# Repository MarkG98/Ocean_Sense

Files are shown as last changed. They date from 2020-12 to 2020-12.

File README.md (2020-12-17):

# Ocean_Sense

Ocean Sense is an ocean-sensing platform which can be placed on a buoy or other ocean science apparatus and sent out to sea for about one week at a time. Many ocean science experiments are run off of buoys or other devices that stand alone in the field for an extended period of time. This board serves as a packaged sensor set that measures and logs three local conditions during the experiments: **temperature, humidity**, and **acceleration**. The board sits ontop of a buoy or equivalent flotation device for the duration of an experiment and then is retrieved. To travel into the depths of the ocean, an appropriate case will need to be engineered.

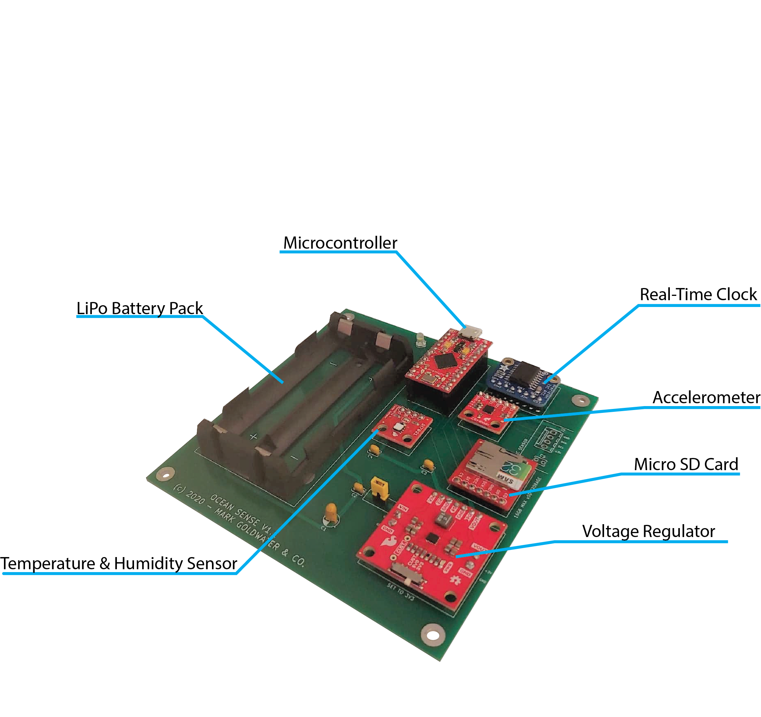
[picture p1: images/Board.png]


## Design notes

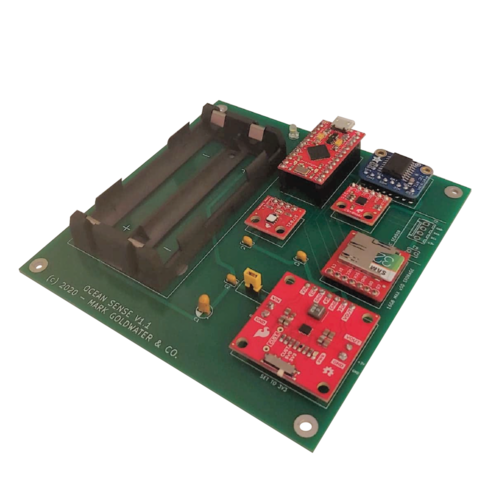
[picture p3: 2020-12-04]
images/BoardCoverView.png

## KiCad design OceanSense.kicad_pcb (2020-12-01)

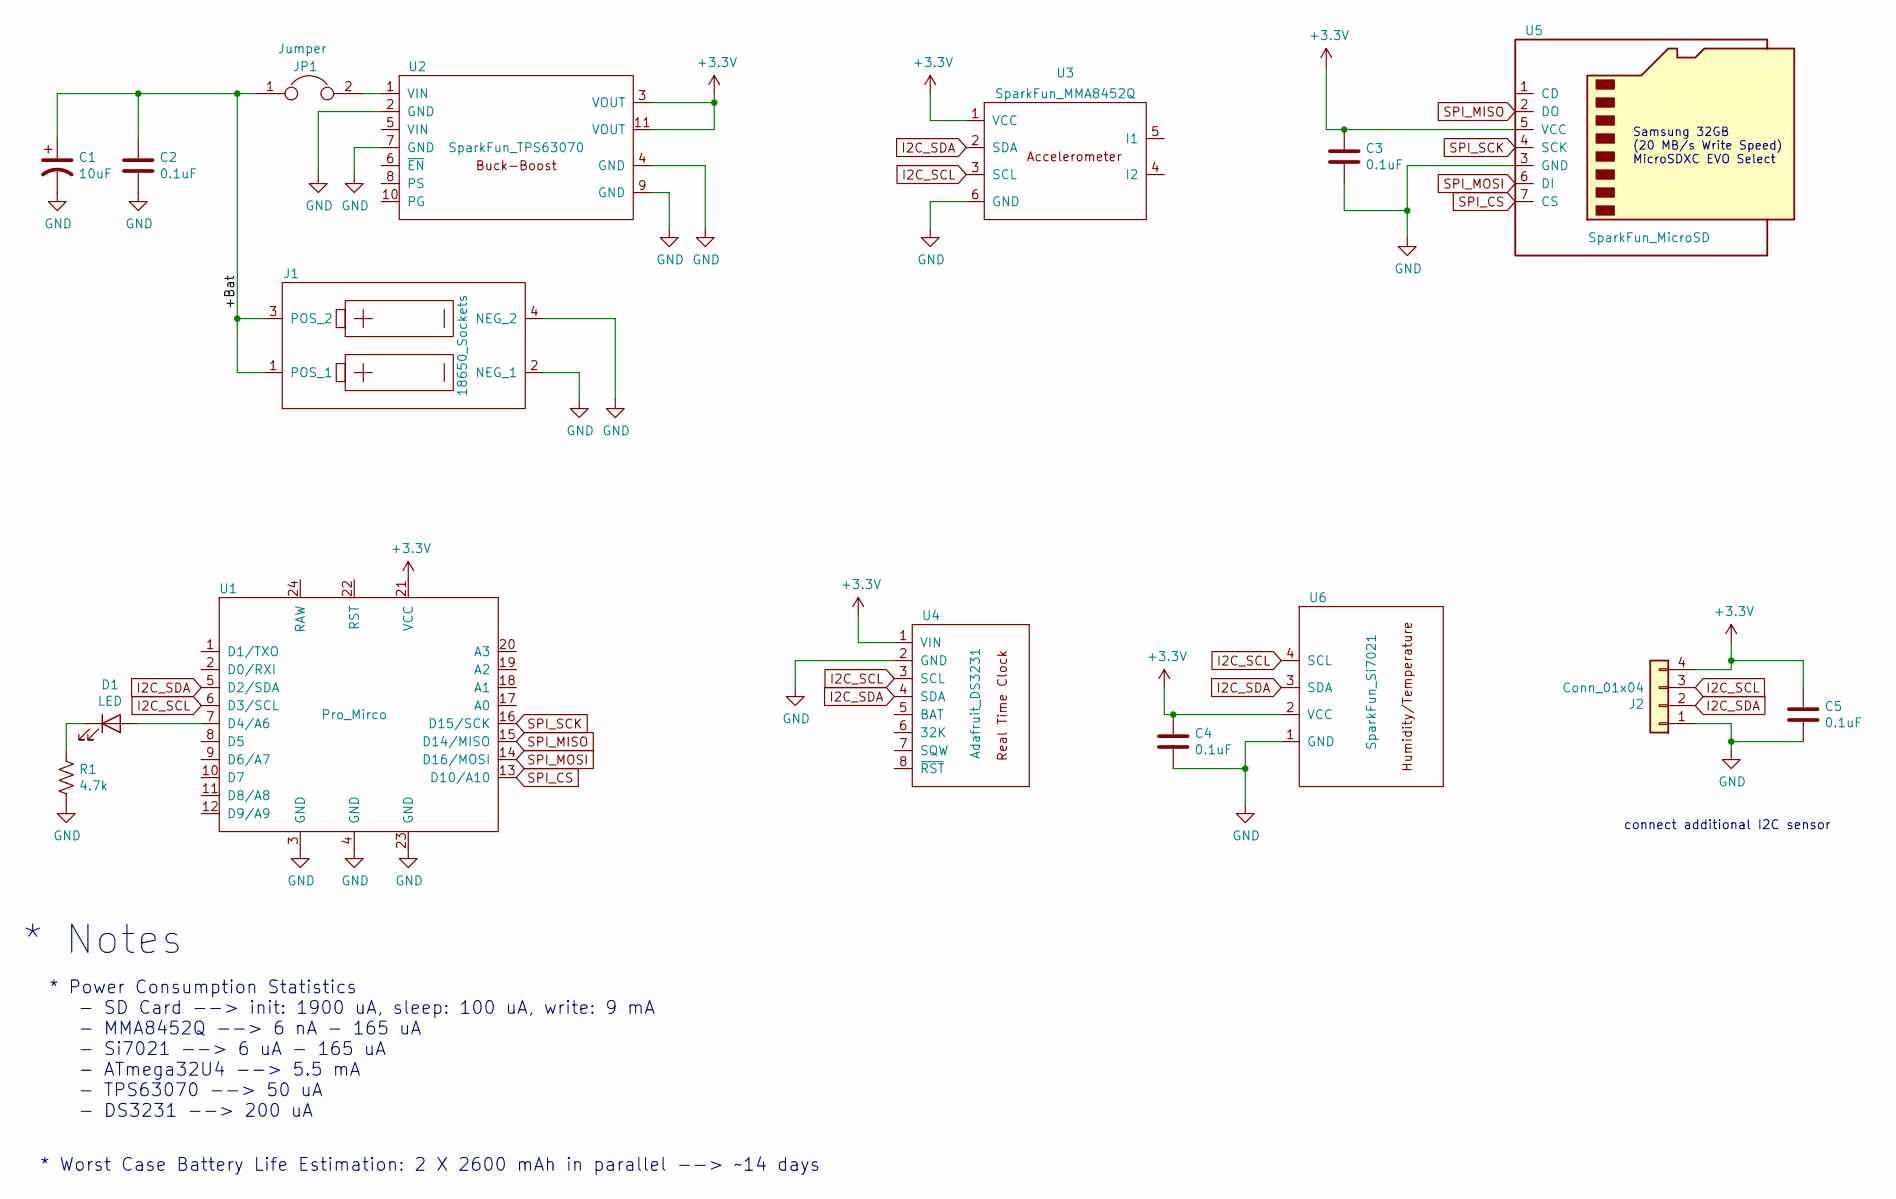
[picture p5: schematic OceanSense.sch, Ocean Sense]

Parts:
C1: 10uF; CP_Radial_D5.0mm_P2.50mm
C2, C3, C4, C5: 0.1uF; C_Rect_L4.0mm_W2.5mm_P2.50mm
D1: LED; LED_D3.0mm
J1: 18650_Sockets; 36-1049-ND
J2: Conn_01x04; Molex_KK-254_AE-6410-04A_1x04_P2.54mm_Vertical
JP1: Jumper
R1: 4.7k; Resistor
U1: Pro_Mirco; Pro Micro
U2: SparkFun_TPS63070; TPS63070
U3: SparkFun_MMA8452Q; MMA8452Q
U4: Adafruit_DS3231; DS3231
U5: SparkFun_MicroSD; uSD Breakout
U6: SparkFun_Si7021; Si7021

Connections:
+3V3: C3.1, C4.1, C5.1, J2.4, U1.21 (VCC), U2.3 (VOUT), U2.11 (VOUT), U3.1 (VCC), U4.1 (VIN), U5.5 (VCC), U6.2 (VCC)
/+Bat: C1.1, C2.1, J1.1 (POS_1), J1.3 (POS_2), JP1.1
GND: C1.2, C2.2, C3.2, C4.2, C5.2, J1.2 (NEG_1), J1.4 (NEG_2), J2.1, R1.2, U1.3 (GND), U1.4 (GND), U1.23 (GND), U2.2 (GND), U2.4 (GND), U2.7 (GND), U2.9 (GND), U3.6 (GND), U4.2 (GND), U5.3 (GND), U6.1 (GND)
I2C_SCL: J2.3, U1.6 (D3/SCL), U3.3 (SCL), U4.3 (SCL), U6.4 (SCL)
I2C_SDA: J2.2, U1.5 (D2/SDA), U3.2 (SDA), U4.4 (SDA), U6.3 (SDA)
unnamed: D1.1 (K), R1.1
unnamed: D1.2 (A), U1.7 (D4/A6)
unnamed: JP1.2, U2.1 (VIN)
SPI_CS: U1.13 (D10/A10), U5.7 (CS)
SPI_MISO: U1.15 (D14/MISO), U5.2 (DO)
SPI_MOSI: U1.14 (D16/MOSI), U5.6 (DI)
SPI_SCK: U1.16 (D15/SCK), U5.4 (SCK)

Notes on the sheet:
* Power Consumption Statistics - SD Card --> init: 1900 uA, sleep: 100 uA, write: 9 mA - MMA8452Q --> 6 nA - 165 uA - Si7021 --> 6 uA - 165 uA - ATmega32U4 --> 5.5 mA - TPS63070 --> 50 uA - DS3231 --> 200 uA
Samsung 32GB (20 MB/s Write Speed) MicroSDXC EVO Select
* Worst Case Battery Life Estimation: 2 X 2600 mAh in parallel --> ~~14 days
* Notes
connect additional I2C sensor

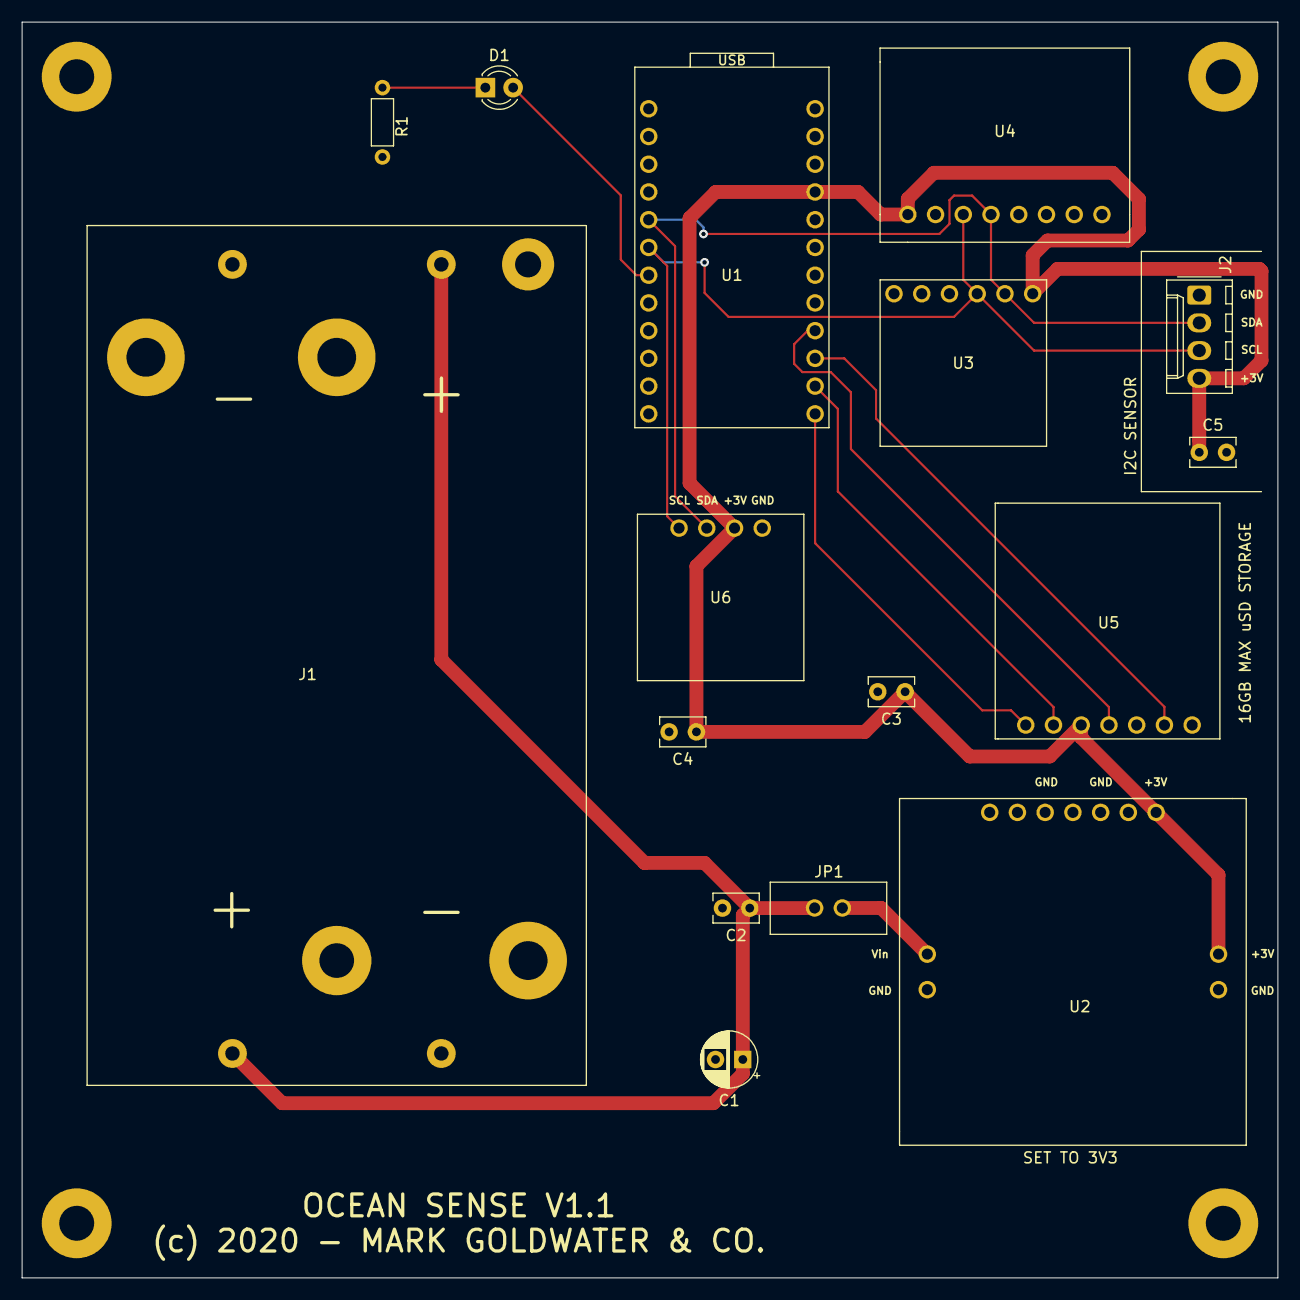
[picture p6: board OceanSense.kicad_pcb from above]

Board: 2 copper layers, 115.0 x 115.0 mm, 16 parts (0 on the bottom side), 12 nets.

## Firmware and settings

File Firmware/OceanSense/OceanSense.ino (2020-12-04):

//      ******************************************************************
//      *                                                                *
//      *                             Ocean Sense                        *
//      *                                                                *
//      *         M. Goldwater                            11/10/2020     *
//      *              Copyright (c) Mark Goldwater & Co., 2020          *
//      *                                                                *
//      ******************************************************************

#include "RTClib.h"
#include "SparkFun_Si7021_Breakout_Library.h"
#include "SparkFun_MMA8452Q.h"
#include <Wire.h>
#include <SPI.h>
#include <SD.h>
#include <string.h>

// #define DEBUG // define for serial port debugging

#define TEMP_HUMID_BUFFER 12 // number of temperature and humidity samples to store before writing to SD card
#define MINUTES_TO_MILLISECONDS 60000 // multiplication factor to convert minutes to milliseconds
#define SECONDS_TO_MILLISECONDS 1000 // multiplication factor to convert seconds to milliseconds

//
// create real-time clock object
//
RTC_DS3231 rtc;

//
// create temperature and humidity sensor object
//
Weather tempHumid;

//
// create accel object
//
MMA8452Q accel;

//
// pin assignments
//
const int SPI_CS_PIN = 10;
const int LED_PIN = 4;

//
// SD card file object
//
File logFile;

//
// buffers for intermittent termperature and humidity measurements as well as timestamps
//
char timeStamps[TEMP_HUMID_BUFFER][30];
char timeStamp[30];
float temperatures[TEMP_HUMID_BUFFER];
float humidities[TEMP_HUMID_BUFFER];

void setup() {
   
   //
   // start serial monitor
   // wait for it to connect. Needed for nativ USB
   //
   #ifdef DEBUG
   Serial.begin(9600);
   while (!Serial);
   #endif

   //
   // configure pins
   //
   pinMode(LED_PIN, OUTPUT);

   
   digitalWrite(LED_PIN, HIGH);

   //
   // initialize and begin temperature and humidity sensor
   //
   tempHumid.begin();
   delay(200);

   //
   // check accelerometer
   //
   if (accel.begin() == false) {
    #ifdef DEBUG
    Serial.println("Accel not connected");
    #endif
    while(1);
   }
   
   //
   // initialize the SD card
   //
   #ifdef DEBUG
   Serial.println("Initializing SD Card...");
   #endif
   if (!SD.begin(SPI_CS_PIN)) {
      #ifdef DEBUG
      Serial.println("Initialization Failed");
      #endif
      while(1);
   }
   #ifdef DEBUG
   Serial.println("Initialization Done.");
   #endif
   delay(200);

   //
   // check for config file
   //
   if (SD.exists("config.txt")) {
     processConfgurationFile();
   }

   //
   // set up CSV columns
   //
   if (!SD.exists("logth.csv")) {
    setUpTempHumidCsvColumns();
   }
   delay(1000);
   if (!SD.exists("loga.csv")) {
    setUpAccelCsvColumns();
   }
}

void loop() {
  //
  // main function to run the OceanSense platform
  //
  collectData();
}

// ********************************************************************
// |                    DATA COLLECTION FUNCTION                      |
// ********************************************************************

void collectData() {
  //
  // counter to index into buffer
  // 
  unsigned short buffer_counter = 0;

  //
  // setup timers for temperature and humidity data collection
  //
  const unsigned long update_temp_humid_period = 0.5 * MINUTES_TO_MILLISECONDS; // left coefficient [minutes] varies how often teperature and humidity data is collected
  unsigned long update_timer_temp_humid = millis();
  unsigned long elapsed_time_temp_humid;
  
  //
  // setup timers for accelerometer data collection
  //
  const unsigned long update_accelerometer_period = 1 * MINUTES_TO_MILLISECONDS; // left coefficient [minutes] varies how often accelerometer data is collected
  const unsigned long accelerometer_data_collection_period = 5 * SECONDS_TO_MILLISECONDS; // left coefficient [seconds] varies how long accelerometer data is collected for
  unsigned long update_timer_accelerometer_period = millis();
  unsigned long elapsed_time_accelerometer;

  //
  // setup timers to blink LED
  //
  const unsigned long update_LED_period = 2 * SECONDS_TO_MILLISECONDS; // left coefficient [seconds] varies the period of the LED blink
  const unsigned long LED_blink_period = 250; // left coefficient [milliseconds] varies how long the LED stays on for in its blink
  unsigned long update_timer_LED = millis();
  unsigned long elapsed_time_LED;
  
  //
  // flags for data collection
  //
  bool collect_accel = false;
  bool collect_temp_and_humid = false;
  bool LED_on = false;

  //
  // main data colletion loop
  //
  while(1) {
    if (buffer_counter == TEMP_HUMID_BUFFER) {
      //
      // when buffer is filled unload to SD card
      //
      writeTemperatureAndHumidityToSD();

      //
      // reset buffer index counter
      //
      buffer_counter = 0;
    }

    //
    // log temperature and humidity data on timer
    //
    if (collect_temp_and_humid) {
      logTemperatureAndHumidity(buffer_counter);
      #ifdef DEBUG
      Serial.print(temperatures[buffer_counter]);
      Serial.print(" ");
      Serial.println(humidities[buffer_counter]);
      Serial.println(timeStamps[buffer_counter]);
      #endif
      
      //
      // iterate buffer index
      // 
      buffer_counter += 1;

      //
      // stop temp/humidity data collection
      //
      collect_temp_and_humid = false;
    }

    //
    // log accelerometer data on timer
    //
    if (collect_accel) {
      logAndWriteAccelerometerToSD();
    }
    
    //
    // timer to flip flag for collection of temperature an humidity data
    //
    elapsed_time_temp_humid = millis() - update_timer_temp_humid;
    if (elapsed_time_temp_humid >= update_temp_humid_period) {
      collect_temp_and_humid = true;
      update_timer_temp_humid = millis();
    }

    //
    // timer to flip flag ON for collection of accelerometer data 
    //
    if (collect_accel == false) {
      elapsed_time_accelerometer = millis() - update_timer_accelerometer_period;
      if (elapsed_time_accelerometer >= update_accelerometer_period) {
         collect_accel = true;
         update_timer_accelerometer_period = millis();
      }
    } else {
      //
      // timer to flip flag OFF for collection of accelerometer data
      //
      elapsed_time_accelerometer = millis() - update_timer_accelerometer_period;
      if (elapsed_time_accelerometer >= accelerometer_data_collection_period) {
         collect_accel = false;
         update_timer_accelerometer_period = millis();
      }
    }

    //
    // timer to turn ON the LED
    //
    if (LED_on == false) {
      elapsed_time_LED = millis() - update_timer_LED;
      if (elapsed_time_LED >= update_LED_period) {
         digitalWrite(LED_PIN, HIGH);
         LED_on = true;
         update_timer_LED = millis();
      }
    } else {
      //
      // timer to turn OFF the LED
      //
      elapsed_time_LED = millis() - update_timer_LED;
      if (elapsed_time_LED >= LED_blink_period) {
         digitalWrite(LED_PIN, LOW);
         LED_on = false;
         update_timer_LED = millis();
      }
    }
  }
}

// ********************************************************************
// |                          HELPER FUNCTIONS                        |
// ********************************************************************

void writeTemperatureAndHumidityToSD() {
  #ifdef DEBUG
  Serial.println("Writing Temperature and Humidity Data to SD Card.");
  #endif

  //
  // open temperature and humidity log file
  //
  logFile = SD.open("logth.csv", FILE_WRITE);

  //
  // if log file opened properly unload buffers
  //
  if (logFile) {
    for (int i = 0; i < TEMP_HUMID_BUFFER; i++) {
      logFile.print(timeStamps[i]);
      logFile.print(", ");
      logFile.print(temperatures[i]);
      logFile.print(", ");
      logFile.println(humidities[i]);
    }

    //
    // close file
    //
    logFile.close();
    #ifdef DEBUG
    Serial.println("Done.");
    #endif
  } else {
    #ifdef DEBUG
    Serial.println("Error opening log file");
    #endif
  }
}

void logAndWriteAccelerometerToSD() {
  //
  // open temperature and humidity log file
  //
  logFile = SD.open("loga.csv", FILE_WRITE);

  //
  // if log file opened properly take data
  //
  if (logFile) {
    if (accel.available()) {
      getTimeStamp();
      logFile.print(timeStamp);
      logFile.print(", ");
      logFile.print(accel.getCalculatedX(), 3);
      logFile.print(", ");
      logFile.print(accel.getCalculatedY(), 3);
      logFile.print(", ");
      logFile.print(accel.getCalculatedZ(), 3);
      logFile.println();
    }
    
    //
    // close file
    //
    logFile.close();
  } else {
    #ifdef DEBUG
    Serial.println("Error opening log file");
    #endif
  }
}

void getTimeStamp() {
   //
   // get current time from RTC
   //
   DateTime now = rtc.now();

   //
   // format timestamp and store it
   //
   snprintf(timeStamp, sizeof(timeStamp), "%02d/%02d/%04d %02d:%02d:%02d", now.month(), now.day(), now.year(), now.hour(), now.minute(), now.second());
}

void updateTimeStamp(unsigned short buffer_index) {
   //
   // get current time from RTC
   //
   DateTime now = rtc.now();

   //
   // format timestamp and store it
   //
   snprintf(timeStamps[buffer_index], sizeof(timeStamps[buffer_index]), "%02d/%02d/%04d %02d:%02d:%02d", now.month(), now.day(), now.year(), now.hour(), now.minute(), now.second());
}

void logTemperatureAndHumidity(unsigned short buffer_index) {
   //
   // measure humidity and temperature
   //
   float humidity = tempHumid.getRH();
   float temperature = tempHumid.getTempF();

   //
   // add humidity and temperature measurements to respectie buffers
   //
   humidities[buffer_index] = humidity;
   temperatures[buffer_index] = temperature;
   
   //
   // add timestamp to timestamp buffer
   //
   updateTimeStamp(buffer_index);
}

void processConfgurationFile() {
  //
  // configure buffers for reading config file
  //
  char* configBuff;
  char* token;
  char* DATE;
  char* TIME;
  unsigned short apply;
  
     
  logFile = SD.open("config.txt");
  if (logFile) {
    //
    // get the file size
    //
    unsigned int fileSize = logFile.size();

    //
    // create buffer to read the file
    //
    configBuff = (char*) malloc(fileSize + 1);

    //
    // read the file into the buffer
    //
    logFile.read(configBuff, fileSize);

    //
    // add string terminator when done writing to buffer
    //
    configBuff[fileSize] = '\0';

    //
    // close the file
    //
    logFile.close();
  } else {
   #ifdef DEBUG
   Serial.print("Error Opening Configuration File");
   #endif
  }

  //
  // pull first token using deliminators '=' and '\n'
  //
  token = strtok(configBuff, "=\n");

  //
  // while the token exists, parse the config file
  //
  while(token != NULL) {
   //
   // store date setting
   //
   if (!strcmp(token, "DATE")) {
     DATE = strtok(NULL, "=\n");
     token = DATE;
   } 

   //
   // store time setting
   //
   if(!strcmp(token, "TIME")) {
     TIME = strtok(NULL, "=\n");
     token = TIME; 
   }

   //
   // store boolean to determine to apply the config or not
   //
   if(!strcmp(token, "APPLY")) {
     apply = atoi(strtok(NULL, "=\n"));
   }

   //
   // get next setting name
   //
   token = strtok(NULL, "=\n");
 }

 //
 // free the config file buffer
 //
 free(configBuff);

 //
 // process config file if apply flag is '1'
 //
 if (apply) {
  rtc.adjust(DateTime(DATE, TIME));
  #ifdef DEBUG
  Serial.println("Applied Config!");
  #endif
 }
}

void setUpAccelCsvColumns() {
  
  //
  // open acceleration log file
  //
  logFile = SD.open("loga.csv", FILE_WRITE);

  //
  // if log file opened properly write columns
  //
  if (logFile) {
    logFile.print("TimeStamp, ");
    logFile.print("X, ");
    logFile.print("Y, ");
    logFile.print("Z, ");
    logFile.println();
    
    //
    // close file
    //
    logFile.close();
  } else {
    #ifdef DEBUG
    Serial.println("Error opening accel log file");
    #endif
  }
}

void setUpTempHumidCsvColumns() {
  //
  // open acceleration log file
  //
  logFile = SD.open("logth.csv", FILE_WRITE);

  //
  // if log file opened write columns
  //
  if (logFile) {
    logFile.print("TimeStamp, ");
    logFile.print("Temp, ");
    logFile.print("Humidity, ");
    logFile.println();
    
    //
    // close file
    //
    logFile.close();
  } else {
    #ifdef DEBUG
    Serial.println("Error opening th log file");
    #endif
  }
}

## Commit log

2020-12-01 Push current project
    [OceanSense-B_Cu.gbr, OceanSense-B_Mask.gbr, OceanSense-B_SilkS.gbr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]
2020-12-04 Adding board image
2020-12-04 Added board image
2020-12-17 Fixing board image

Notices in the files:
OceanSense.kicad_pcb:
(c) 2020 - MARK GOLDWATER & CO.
